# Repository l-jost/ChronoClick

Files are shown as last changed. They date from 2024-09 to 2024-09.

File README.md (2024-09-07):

# ChronoClick

> [!NOTE]
> Currently the project is still in the requirement and concept phase!

## Overview
Concept

**ChronoClick** is a compact, user-friendly, and versatile reminder device designed to help users stay on top of routine tasks like watering plants, feeding pets, or taking medication. Powered by a CR2032 battery, the device features a full color display that counts down and counts up time, providing a simple yet effective way to track when an action is due or overdue.

## Project Goals
The primary aim of this project is to establish a comprehensive framework for hardware and software development, starting from the initial concept and progressing through every stage. It will encompass all essential steps, including conceptual design, requirements engineering, system development, software engineering and the integration of automated testing processes. This project is designed to serve as a baseline, to successfully develop a hardware system from the ground up.

## Features
- **Countdown Timer:** Set a custom countdown to track time for any task.
- **One-Click Reset:** Simply press the button to reset the timer and start the countdown again.
- **NFC Communication:** To configure the device and upload custom icons using any phone.
- **Full color reflective LCD:** The button changes color when the countdown reaches zero, providing a clear, visual alert.
- **1 Year Battery Life:** Powered by a CR2032 coin cell.

## Open Source
Everything is open source and available for free use under the [GPL-3.0 License](https://github.com/l-jost/ChronoClick/blob/main/LICENSE.md). Please note that it is provided without any warranty.

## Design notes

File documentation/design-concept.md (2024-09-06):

# Design Concept

## Table of Contents
- [Concept](#concept)
- [Button](#button)
- [Block Diagram](#block-diagram)
- [Feasibility](#feasibility)
    - [Power](#power)
        - [Battery](#battery)
        - [Microcontroller](#microcontroller)
        - [Display](#display)
        - [Power Conversion](#power-conversion)
        - [Typical Operation](#typical-operation)
        - [Runtime Estimation](#runtime-estimation)

## Concept
Concept

**ChronoClick** is a compact, user-friendly, and versatile reminder device designed to help users stay on top of routine tasks like watering plants, feeding pets, or taking medication. Powered by a CR2032 battery, the device features a full color display that counts down and counts up time, providing a simple yet effective way to track when an action is due or overdue.

### Button
| Feature | Physical Button | Capacitive Button with Haptic Motor |
|---|---|---|
| **Tactile Feedback** | Immediate, mechanical feedback | Customizable haptic feedback |
| **Power Consumption** | Low power consumption | Higher power consumption due to sensor and motor |
| **Complexity** | Simple circuitry, but very difficult mechanical design to guide housing and making it feel good | More complex circuitry, quite easy mechanical design |

We should not use a haptic motor because we are very much power and energy limited!

## Block Diagram
Block Diagram

## Feasibility

### Power
The device needs to operate at least 1 year on a CR2032 battery. For that reason everything needs to be extremely power efficient.

#### Battery
A typical CR2032 battery has a capacity of **225mAh** and a nominal voltage range of 2V-3.3V with a nominal voltage of **~2.9V**.
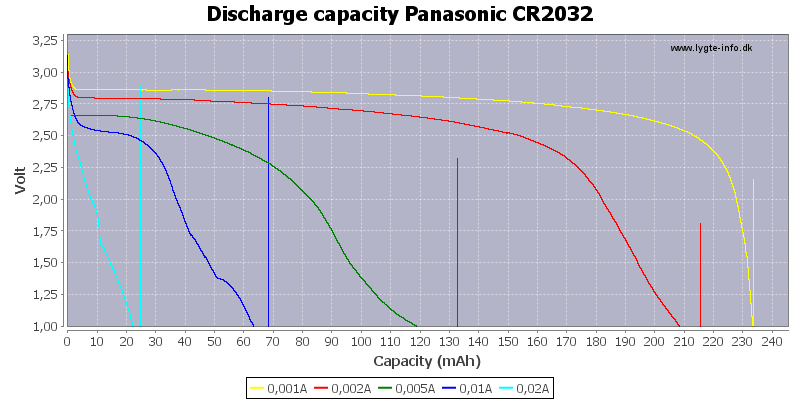
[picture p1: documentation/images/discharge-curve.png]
Discharge Curve


#### Microcontroller
The [STM32U0](https://www.st.com/en/microcontrollers-microprocessors/stm32u0-series.html) series offers excellent power consumption figures and are used here for some baseline figures.
| **Operating Mode** | **Current Consumption** |
|---|---|
| Standby with RTC | 160 nA |
| Run @ 4 MHz| 350 uA |
| GPIO | 0.6 uA/MHz |
| SPI | 1.8 uA/MHz |
| I2C | 1.1 uA/MHz |
| Analog | 1.9 uA/MHz |

#### Display
Sharp memory displays are an excellent choice for a fast updating, color display. Especially for the up-count mode the fast update rate is essential. The [new full color displays](https://www.sharpsde.com/products/displays/model/ls012b7dd06a-1-1/#productview) look very nice, they offer 280x280 pixels with 6 bit color! The power consumption however is not great.

| **Mode** | **Typical** | **Max.** |
|---|---|---|
|White display in hold mode|3.4 uW|65 uW|
|White display with 1 Hz update|14 uW|106 uW|

The difference between the typical and the maximum is very large and Sharp offers no explanation. The display will run most of the time in hold mode and only get updated once a minute. As a realistic estimate we will use an average power consumption of **40 uW** for the display.

The [datasheet](https://www.sharpsde.com/fileadmin/products/Displays/Specs/LS014B7DD01_21Dec22_Spec_LCP-0620031B.pdf) does not specify the power rail that consumes the power (3.3V or 5V), therefore we will assume that the power is shared between the two sources.

#### Power conversion
Because of the display we require dual power, 3.3V and 5V. With some [very efficient low power converters](https://www.ti.com/lit/ds/symlink/tps61299.pdf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) from TI, an efficiency of **75%** is possible at currents of 10 uA. For all power conversion calculations we will use 75%.

#### Typical operation
We design the power consumption around the count down mode and ignore the count up, which requires a wake up every second in the first hour.

| **Mode** | **Duration** | **Interval** | **Note** |
|---|---|---|---|
|Fast Display refresh|10 ms|1 min| Only update time characters |
|Full Display refresh|100 ms|4 h|When time expires and resets|
|Configuration|200 ms|10 d|When NFC is used|
|Powered|Always|-|Idle|

#### Runtime estimation
With all the data above we can calculate a theoretical runtime.

The average power consumption is estimated to be **55 uW**, which translates to a current of **~19 uA** at 2.9V.

Allowing the device to run... **1.2 years!**

The calculation is heavily leaned on a power consumption estimate of the display, since the datasheet does not give enough information to do precise calculations. In addition, quiescent currents for the NFC IC are estimated to be zero because it will be powered by the phone. Quiescent currents for pull-ups and voltage divider needs to be kept below 3uA to reach the 1 year runtime goal. But with that being said, it should be possible to run the device for a year on a single CR2032 coin cell.

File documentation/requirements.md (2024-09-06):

# Device Requirements

Initial draft for the device requirements. This is subject to change!

## Functional Requirements

| ID | Group | Name | Requirement | Rational |
|----|---|---|---|---|
|REQ-01-01|Timer|Count down|The device shall support countdown intervals ranging from 10 minute up to 30 days.|Accommodates various user tasks requiring different time frames.|
|REQ-01-02|Timer|Count up|The device shall support count-up functionality, continuing up to 30 days.|Enables tracking elapsed time since the last action.|
|REQ-01-03|Timer|Count up / down|The device shall count down, prompt the user that the timer expired and then count up.|To show how long overdue the action is.|
|REQ-01-04|Timer|Start / Reset|The device shall have an option to start and reset the timer using a single button|Multiple functions with a minimal interface.|
|REQ-01-05|Interface|Time display|The device shall feature a display that clearly shows time remaining, timer expired status, or count-up time. In addition the the device identification.|The user needs to know!|
|REQ-01-06|Interface|Color Change|The device shall be capable of displaying at least 2 colors.| Improves user recognition and promptness in responding to alerts.|
|REQ-01-07|Interface|Low battery indication|The device shall provide a low battery warning when the battery level drops below 20%, using visual indicators.|Ensures users have adequate time to replace the battery before complete depletion.|
|REQ-01-08|Interface|Single Button|The device shall be operated with a single button.|Very simple but effective interface.|
|REQ-01-09|Interface|Haptic Feedback|The press of the button should have a haptic feedback.|Makes it nicer to use.|
|REQ-01-10|Configuration|App Configuration|The device shall be configurable using a mobile application compatible with both Android.|"Do You Guys Not Have Phones?"|
|REQ-01-11|Configuration|Custom timer intervals|The device shall allow users to set custom time intervals for counting down.|Users need to set different timers for various tasks.|
|REQ-01-12|Configuration|Up / Down configuration|The device shall allow users to select counting modes (count up, count down, or automatic transition) via the mobile app.|Allows user control over timer functionalities.|
|REQ-01-13|Configuration|Persistence|The device shall retain all user configurations and settings in non-volatile memory, ensuring persistence even when the battery is replaced or fully depleted.|Prevents the need for reconfiguration after battery changes, enhancing user convenience.|

## Non-function Requirements
| ID | Group | Name | Requirement | Rational |
|----|---|---|---|---|
|REQ-02-01|Performance|Accuracy|The device shall maintain time accuracy within ±1 second per minute, ±1 minute per hour, and ±1 hour per day.|Clear and testable accuracy specification.|
|REQ-02-02|Performance|Run time|The device shall achieve a minimum battery life of 1 year under typical usage conditions, including continuous timer operation with periodic alerts.|We don't want to replace the battery often.|
|REQ-02-03|Usability|Display accuracy|The device shall adjust display accuracy based on timer settings: display time in seconds for intervals up to 60 minutes, in minutes for intervals up to 24 hours, and in hours for intervals up to 30 days.|Prevents unnecessary precision for longer timers, conserving power and simplifying the display.|
|REQ-02-04|Usability|User|The device shall be simple to use, with setup taking less than 2 minutes.|The device should be easily accessible and intuitive for all users, including those with limited technical skills.|
|REQ-02-05|Usability|Size|The device shall have a diameter not exceeding 30mm and a thickness not exceeding 8mm.|We want something that we can put on many things|
|REQ-02-06|Usability|Battery Replacement|The device shall be designed to allow easy battery replacement without tools.|Nobody wants to use tools to change batteries.|
|REQ-02-07|Usability|Identification|The device shall allow users to assign a unique name or icon to each device via the mobile app, which will be displayed on the screen.|To differentiate between multiple devices in the same location.|
|REQ-02-08|Durability|Drop resistance|The device shall comply with IEC 60068-2-31, ensuring it can withstand drops from a height of 1 meter onto a hard surface without functional damage.|We all drop things.|
|REQ-02-09|Durability|Dust and water intrusion|The device shall be IP4X rated|This ensures the device is robust enough for daily use in different environments.|

## Technical Requirements
| ID | Group | Name | Requirement | Rational |
|----|---|---|---|---|
|REQ-03-01|Power|Power Source|The device shall be powered by a removable CR2032 battery.|Very easy to replace and cheap.|
|REQ-03-02|Interface|Display|The device should feature a round display.|Looks good :)|
|REQ-03-03|Setup|NFC|The device shall be configured using NFC.|Very low power and technology inside most phones.|

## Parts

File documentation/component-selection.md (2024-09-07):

# Component Selection

> [!NOTE]
> This page is work in progress and will change over time

|Component|Name|Datasheet|Notes|
|---|----|---|-----|
|DCDC Converter|TPS61299x/xA|[Link](https://www.ti.com/lit/ds/symlink/tps61299.pdf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)|Extremely efficient even in the micro amp range|
|Inductor|WIP252010P-1R0ML|[Link](https://www.lcsc.com/datasheet/lcsc_datasheet_2304140030_INPAQ-WIP252010P-1R0ML_C315715.pdf)|Recommendation from TI datasheet|
|Microcontroller|STM32U073KC|[Link](https://www.st.com/resource/en/datasheet/stm32u073c8.pdf)|We want all the FLASH and RAM for the high pixel count display|
|Display|LS014B7DD01|[Link](https://www.sharpsde.com/fileadmin/products/Displays/Specs/LS014B7DD01_21Dec22_Spec_LCP-0620031B.pdf)|High density, low power, full color reflective LCD|
|Display Connector|046844721002846+|[Link](https://ele.kyocera.com/assets/products/connector/6844.pdf)|21 Position FPC Connector, 0.3mm pitch|
|NFC|N24RF64E|[Link](https://www.onsemi.com/pdf/datasheet/n24rf64e-d.pdf)|Large Memory, Energy Harvesting and wake-up output|

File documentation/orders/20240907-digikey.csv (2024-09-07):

Id | Item | Quantity | Unit Price | Total Price
1 | NUCLEO-U083RC | 1 | 19.85000 | 19.85000
2 | LS014B7DD01 | 1 | 70.89000 | 70.89000
3 | FPC030P025 | 2 | 12.47000 | 24.94000
4 | 046844721002846+ | 4 | 2.32000 | 9.28000
5 | FIT0096 | 1 | 5.25000 | 5.25000
5 | PREC040SAAN-RC | 4 | 0.92000 | 3.68000

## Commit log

2024-09-01 Remove 1.8V reference
2024-09-07 Orders: Add digikey order
    [20240907-digikey.csv]
2024-09-08 HW: Add altium project for dev project
    [ChronoClick-Development.PrjPcb, ChronoClick-Development_Overview.SchDoc]
